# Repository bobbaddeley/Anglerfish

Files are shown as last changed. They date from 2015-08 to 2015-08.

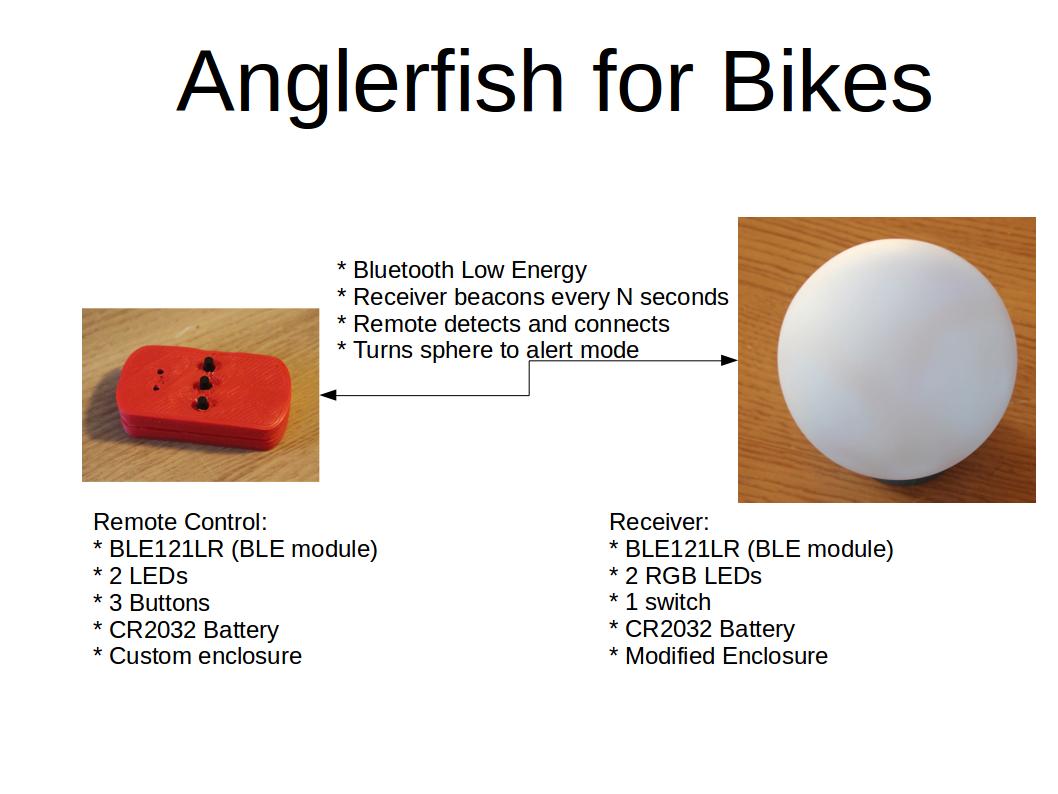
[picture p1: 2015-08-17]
Design_Document.jpg

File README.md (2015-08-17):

# Anglerfish
Anglerfish for Bikes is a project to help people locate their bicycles at night. It uses Bluetooth Low Energy, so you can use either the remote or your smartphone. Simply press the button and the globe on your bike will light up with your customized pattern, letting you know where your bike is.

## Current Status - 2015/08/17

This project is currently at Working Prototype status. The firmware works, the electronics work, the mechanicals work, and in practice it works. There are still a lot of things necessary to turn this from a project to a product. A lot of refinement and cleaning to make the parts easier to assemble, more robust (especially the transmitter), and making it easier to install.

Here's a video of the status, plus it working in a practical situation. Woo! There won't be any additional development until after Burning Man, when I can learn from it in a real environment and figure out what needs to be refined.

## Licenses

Because we use a module, we should be ok with the FCC. The other circuitry may still need to be tested for unintentional transmission, but it's extremely unlikely that it would cause any problems.

Use of the Bluetooth logo is limited, and I think even using the word may be a problem with the Bluetooth SIG. If this project ever seeks commercialization, we'll have to deal with that.

I haven't looked into the use of the Anglerfish name for trademarks, and I haven't looked to see if this idea violates any patents.

I am not using any proprietary or restricted code.

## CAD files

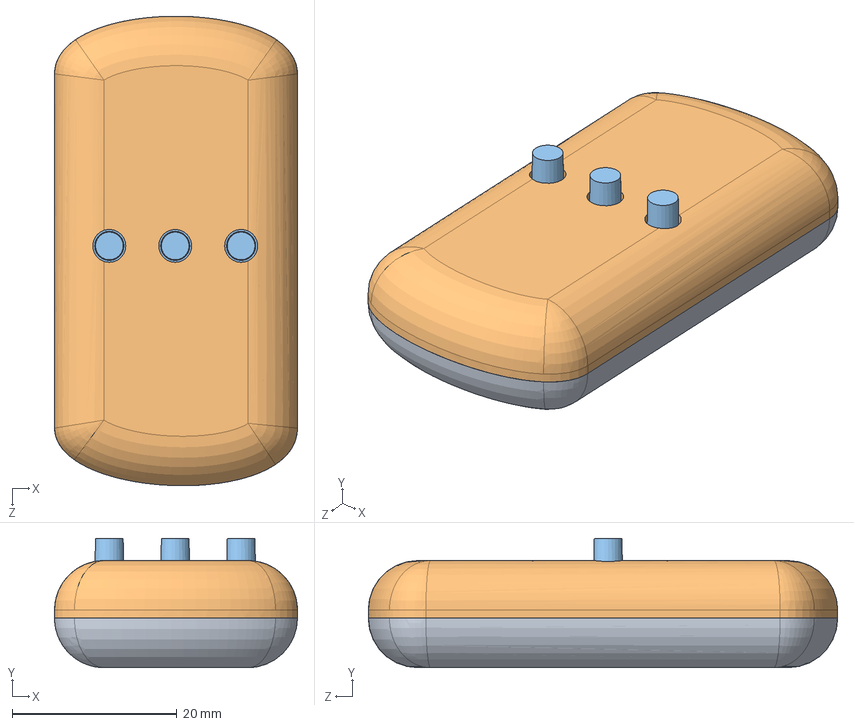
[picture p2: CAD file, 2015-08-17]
enclosure/remote-rounded/Assem1.SLDASM
29.5 x 15.7 x 57.0 mm
bottom
Top
pcb

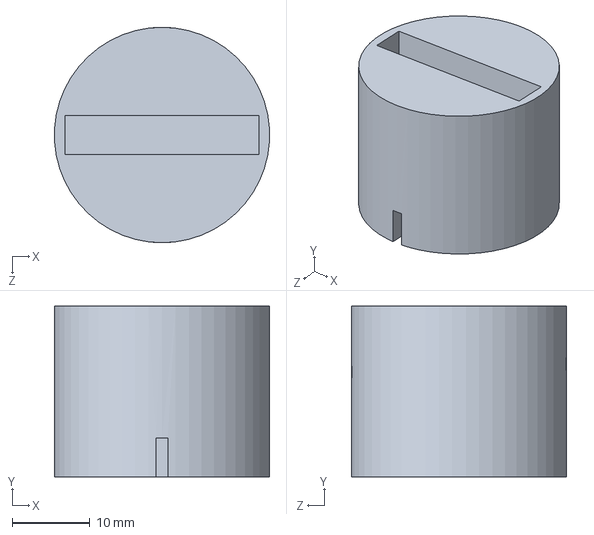
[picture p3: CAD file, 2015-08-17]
enclosure/light/holder.SLDPRT
27.7 x 22.0 x 27.8 mm

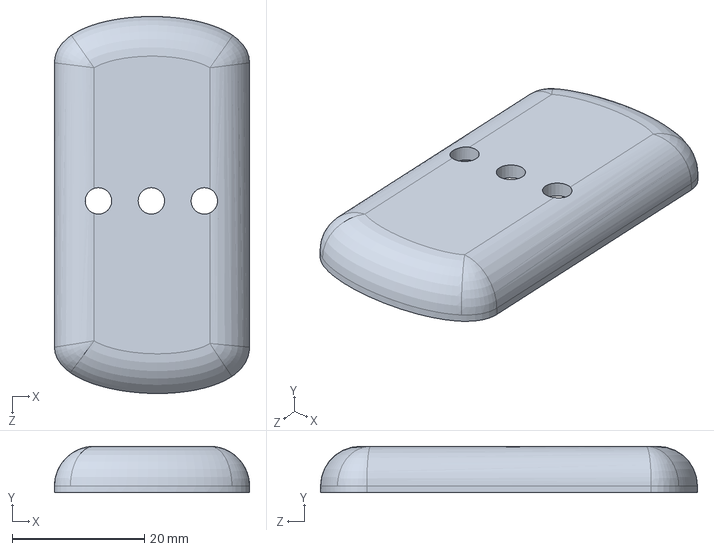
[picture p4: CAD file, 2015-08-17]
enclosure/remote-rounded/Top.sldprt
29.5 x 7.00 x 57.0 mm

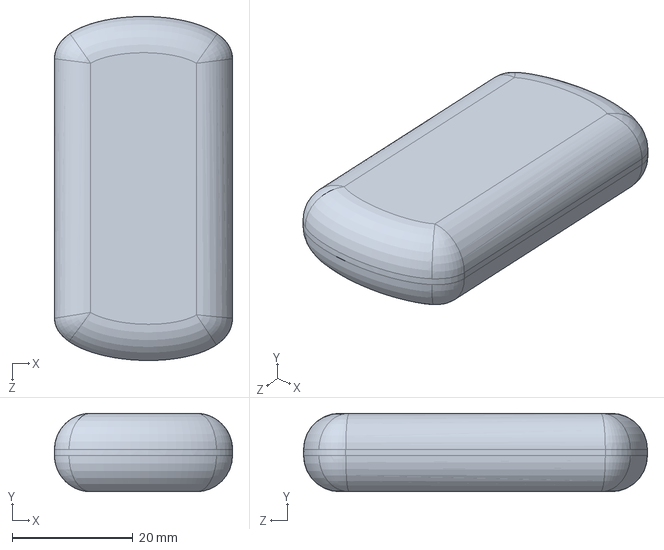
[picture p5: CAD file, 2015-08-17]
enclosure/remote-rounded/shell.SLDPRT
29.5 x 13.0 x 57.0 mm

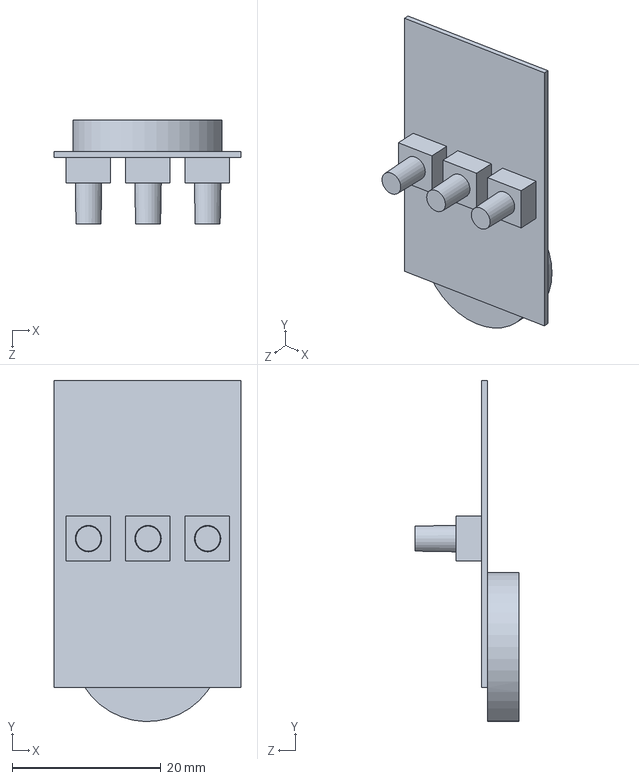
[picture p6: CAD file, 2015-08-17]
enclosure/remote-rounded/pcb.SLDPRT
25.0 x 45.8 x 13.9 mm

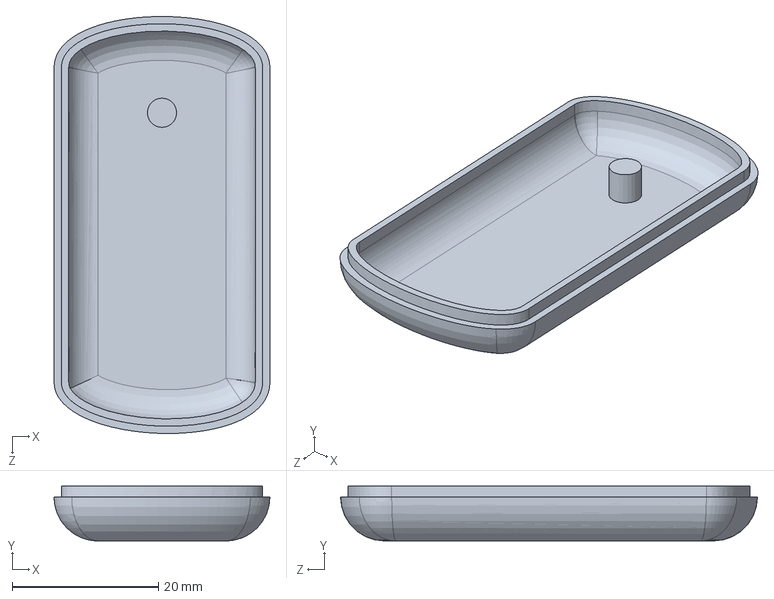
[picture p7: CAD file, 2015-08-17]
enclosure/remote-rounded/bottom.sldprt
29.5 x 7.50 x 57.0 mm

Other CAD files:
enclosure/light/holder.STL
enclosure/remote-rounded/Top.STL
enclosure/remote-rounded/bottom.STL

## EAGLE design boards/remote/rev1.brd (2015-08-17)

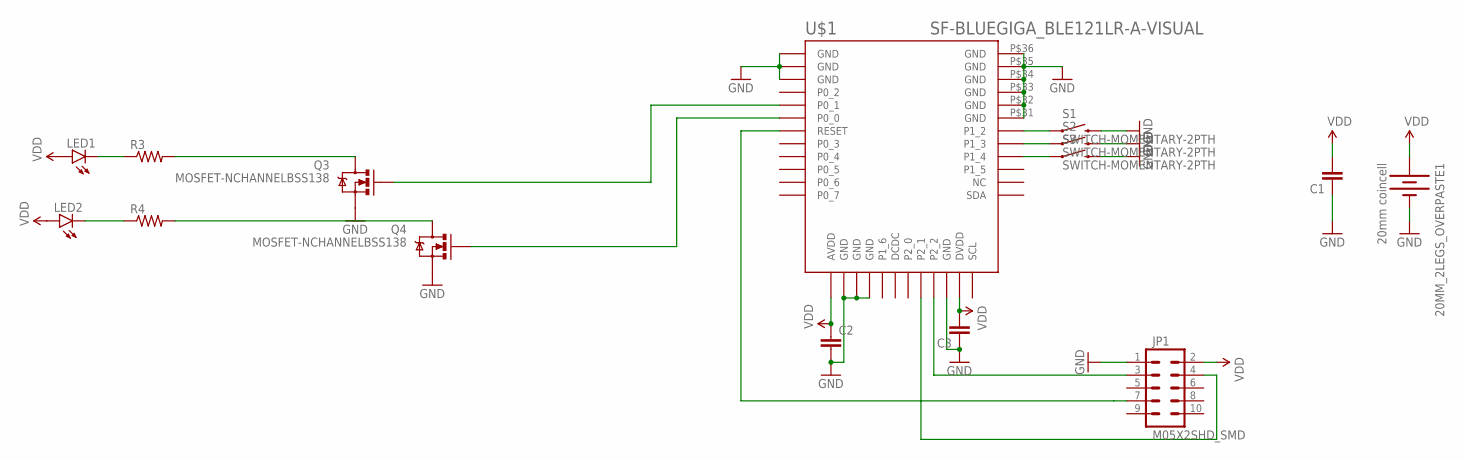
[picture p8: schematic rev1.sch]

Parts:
20MM_2LEGS_OVERPASTE1: 20mm coincell; BATTCON_20MM_4LEGS
C1: CAP1206; 1206
C2, C3: CAP0603-CAP; 0603-CAP
JP1: M05X2SHD_SMD; 2X5-SHROUDED_SMD
LED1, LED2: LED1206; LED-1206
Q3, Q4: MOSFET-NCHANNELBSS138; SOT23-3
R3, R4: RESISTOR0603; 0603-RES
S1, S2, S3: SWITCH-MOMENTARY-2PTH; TACTILE-PTH
U$1: SF-BLUEGIGA_BLE121LR-A-VISUAL; SF-BLUEGIGA_BLE121LR-A

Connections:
GND: 20MM_2LEGS_OVERPASTE1.2 (-), C1.1, C2.2, C3.1, JP1.1, Q3.2 (S), Q4.2 (S), S1.3 (2), S2.3 (2), S3.3 (2), U$1.P$1 (GND), U$1.P$2 (GND), U$1.P$3 (GND), U$1.P$14 (GND), U$1.P$15 (GND), U$1.P$16 (GND), U$1.P$22 (GND), U$1.P$31 (GND), U$1.P$32 (GND), U$1.P$33 (GND), U$1.P$34 (GND), U$1.P$35 (GND), U$1.P$36 (GND)
unnamed: Q4.1 (G), U$1.P$6 (P0_0)
unnamed: S1.1, U$1.P$30 (P1_2)
unnamed: S2.1, U$1.P$29 (P1_3)
unnamed: S3.1, U$1.P$28 (P1_4)
unnamed: Q3.3 (D), R3.2
unnamed: Q4.3 (D), R4.2
unnamed: Q3.1 (G), U$1.P$5 (P0_1)
unnamed: LED1.C, R3.1
unnamed: JP1.3, U$1.P$21 (P2_2)
unnamed: JP1.4, U$1.P$20 (P2_1)
unnamed: JP1.7, U$1.P$7 (RESET)
unnamed: LED2.C, R4.1
VDD: 20MM_2LEGS_OVERPASTE1.1 (+), C1.2, C2.1, C3.2, JP1.2, LED1.A, LED2.A, U$1.P$13 (AVDD), U$1.P$23 (DVDD)

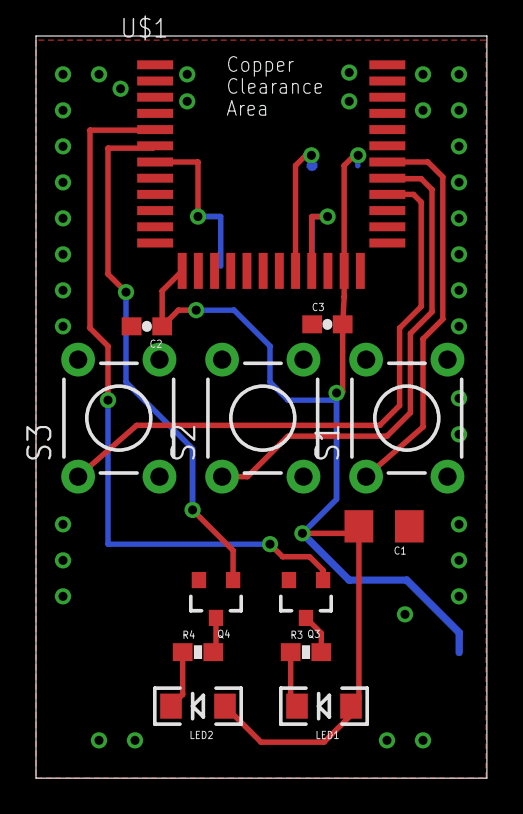
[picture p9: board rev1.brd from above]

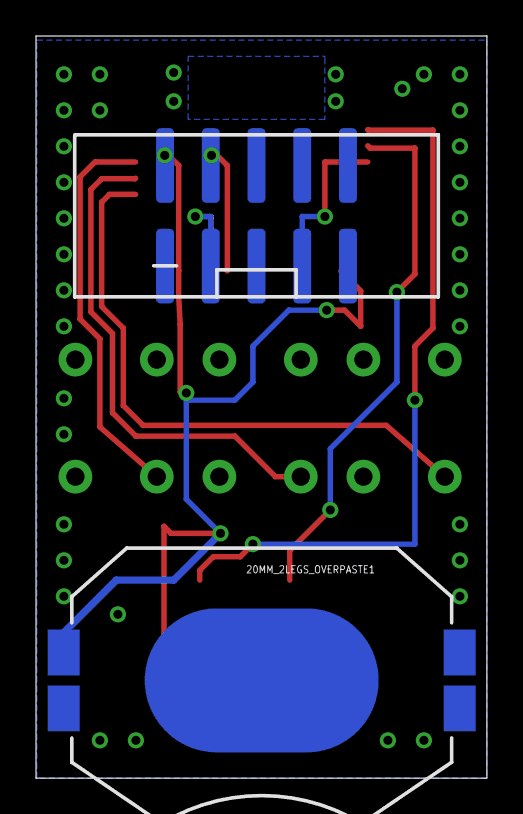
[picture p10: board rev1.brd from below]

Board: 2 copper layers, 25.1 x 41.2 mm, 15 parts (2 on the bottom side), 14 nets.

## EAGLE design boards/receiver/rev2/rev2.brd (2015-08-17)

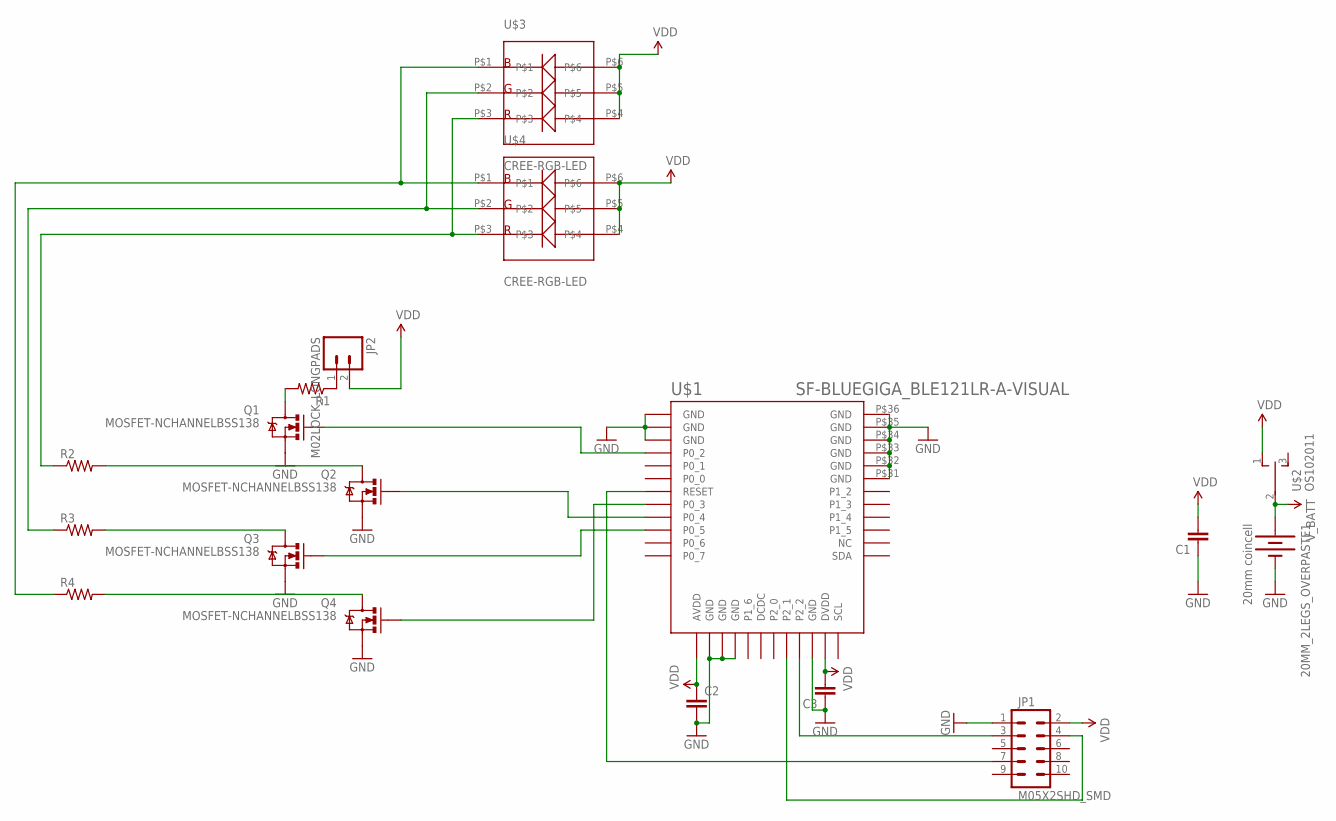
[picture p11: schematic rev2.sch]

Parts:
20MM_2LEGS_OVERPASTE1: 20mm coincell; BATTCON_20MM_4LEGS
C1: CAP1206; 1206
C2, C3: CAP0603-CAP; 0603-CAP
JP1: M05X2SHD_SMD; 2X5-SHROUDED_SMD
JP2: M02LOCK_LONGPADS; 1X02_LOCK_LONGPADS
Q1, Q2, Q3, Q4: MOSFET-NCHANNELBSS138; SOT23-3
R1, R2, R3, R4: RESISTOR0603; 0603-RES
U$1: SF-BLUEGIGA_BLE121LR-A-VISUAL; SF-BLUEGIGA_BLE121LR-A
U$2: OS102011
U$3, U$4: CREE-RGB-LED

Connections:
GND: 20MM_2LEGS_OVERPASTE1.2 (-), C1.1, C2.2, C3.1, JP1.1, Q1.2 (S), Q2.2 (S), Q3.2 (S), Q4.2 (S), U$1.P$1 (GND), U$1.P$2 (GND), U$1.P$3 (GND), U$1.P$14 (GND), U$1.P$15 (GND), U$1.P$16 (GND), U$1.P$22 (GND), U$1.P$31 (GND), U$1.P$32 (GND), U$1.P$33 (GND), U$1.P$34 (GND), U$1.P$35 (GND), U$1.P$36 (GND)
unnamed: Q1.3 (D), R1.2
unnamed: Q2.3 (D), R2.2
unnamed: Q3.3 (D), R3.2
unnamed: Q4.3 (D), R4.2
unnamed: Q4.1 (G), U$1.P$8 (P0_3)
unnamed: Q3.1 (G), U$1.P$10 (P0_5)
unnamed: Q2.1 (G), U$1.P$9 (P0_4)
unnamed: Q1.1 (G), U$1.P$4 (P0_2)
unnamed: JP2.1, R1.1
unnamed: R2.1, U$3.P$3, U$4.P$3
unnamed: R3.1, U$3.P$2, U$4.P$2
unnamed: JP1.3, U$1.P$21 (P2_2)
unnamed: JP1.4, U$1.P$20 (P2_1)
unnamed: JP1.7, U$1.P$7 (RESET)
unnamed: R4.1, U$3.P$1, U$4.P$1
VDD: C1.2, C2.1, C3.2, JP1.2, JP2.2, U$1.P$13 (AVDD), U$1.P$23 (DVDD), U$2.1 (O), U$3.P$4, U$3.P$5, U$3.P$6, U$4.P$4, U$4.P$5, U$4.P$6
V_BATT: 20MM_2LEGS_OVERPASTE1.1 (+), U$2.2

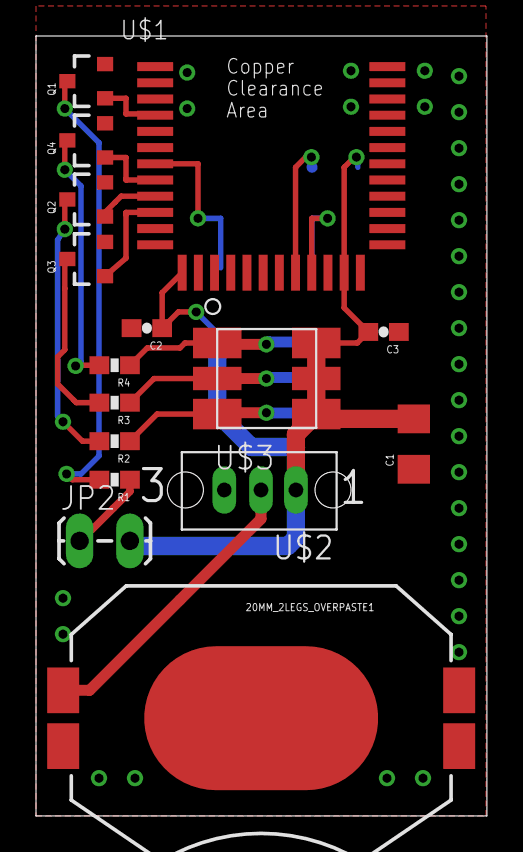
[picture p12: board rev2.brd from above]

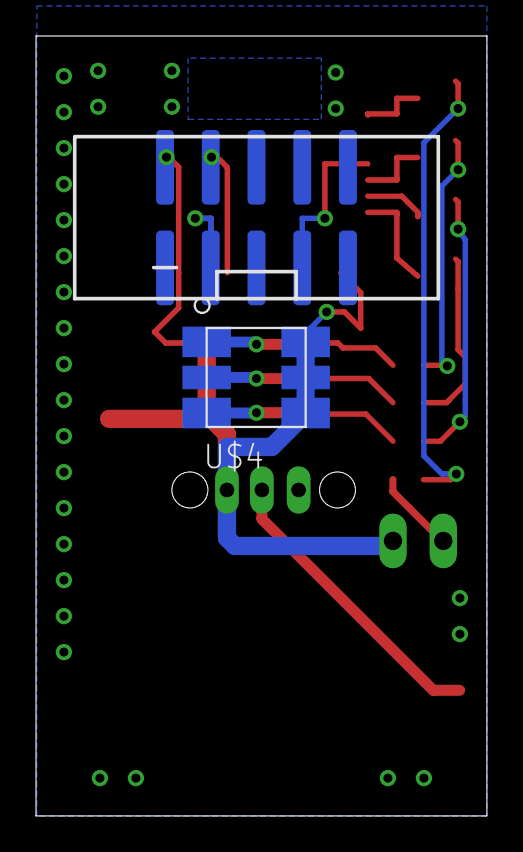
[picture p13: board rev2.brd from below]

Board: 2 copper layers, 25.1 x 43.3 mm, 18 parts (2 on the bottom side), 18 nets.

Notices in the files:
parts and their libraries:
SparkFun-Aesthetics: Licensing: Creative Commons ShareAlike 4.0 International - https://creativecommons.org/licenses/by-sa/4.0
